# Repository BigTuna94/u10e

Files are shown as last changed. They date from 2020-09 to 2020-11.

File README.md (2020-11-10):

# μ10e

The μ10e, pronounced *Mutiny*, is another take on a DIY ergonomic ortholinear with column stagger split keyboard inspired by such boards as the ErgoDox, Crkbd, Splitreus62, and even the Planck and Boardwalk.

### Sample Layout
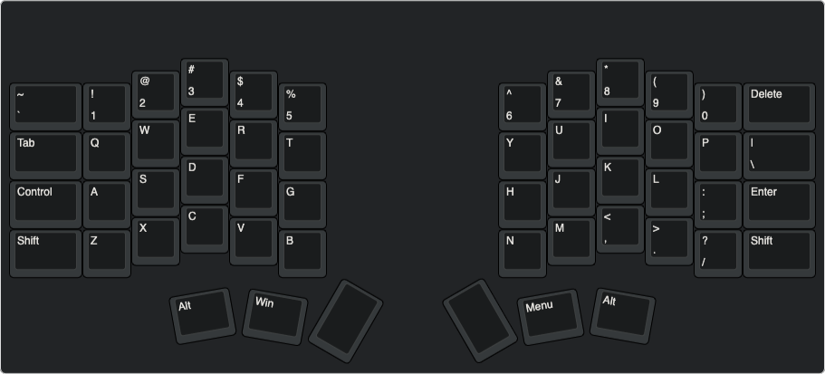
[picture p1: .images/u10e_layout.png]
u10eLayout


### Current PCB Design
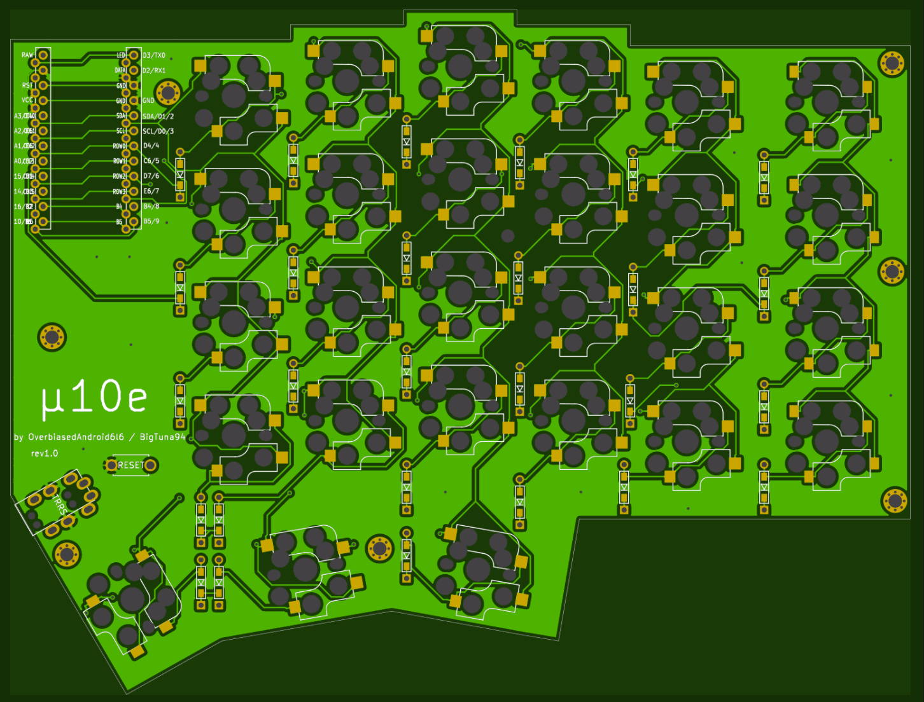
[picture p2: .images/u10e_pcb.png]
u10ePCB


### Goals
The initial inspiration for this board was a Crkbd with 1.5U modifiers, a number row, and Kailh Choc sockets. However, after seeing designs like the Lily58, I've decided it would be even better to support both Choc and MX sockets on the same pcb.

Although the first revision of this board will use a socketed Pro Micro footprint MCU per side, the overall goal of this project is something a little more sofisticated.

### Roadmap
- [x] Create initial schematic and pcb design using pro micro
- [ ] Gather feedback from community

### Potential Future Features
- Encoder footprint below controller
- Move TRRS footprint
- OLED footprint below contoller
- Built in MCU
  - The nice!nano and other new USB-C boards are really good right now.
  - Even though I like this idea, I'll see if there is community interest

### rev1.0 Images
#### MX Mounts
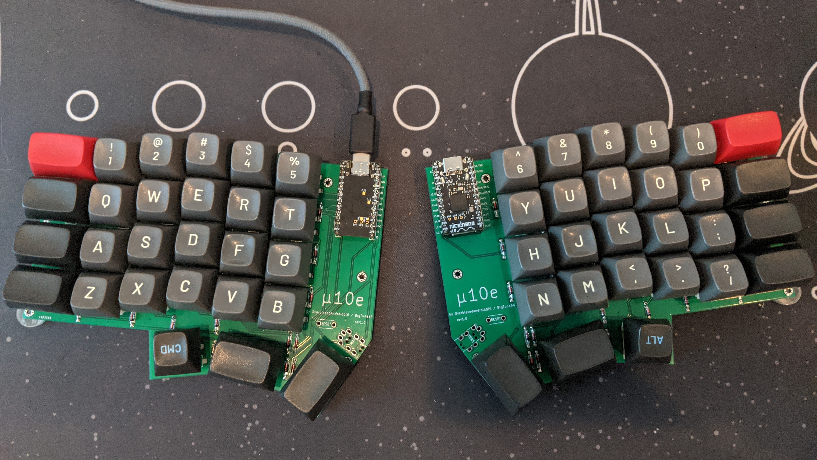
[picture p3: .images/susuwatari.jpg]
MT3 Susuwatari

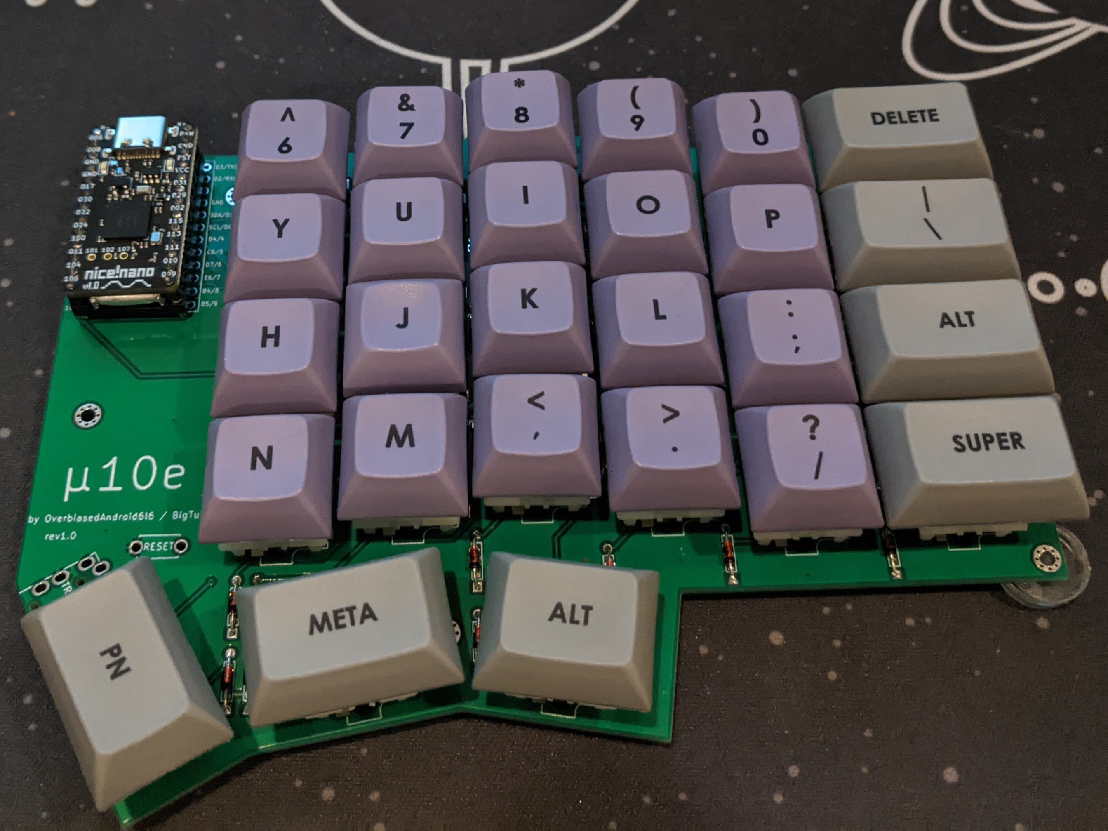
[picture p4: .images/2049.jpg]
DSA 2049

#### Choc Mounts
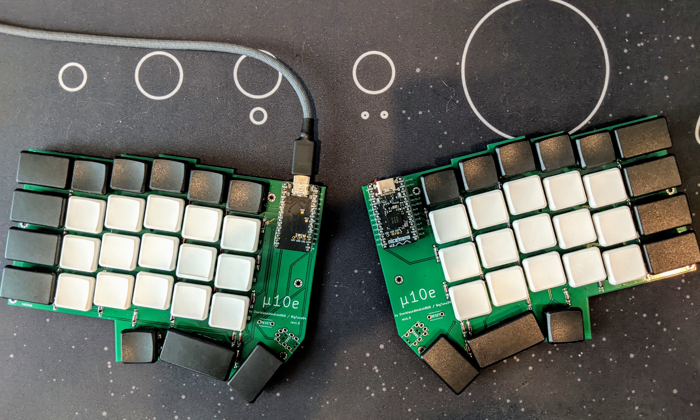
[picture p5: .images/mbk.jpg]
mbk

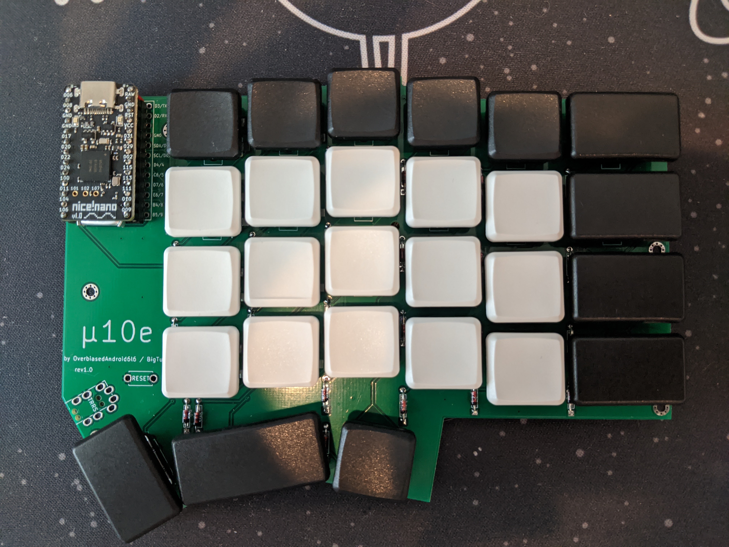
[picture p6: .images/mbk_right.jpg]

#### Socket Closeup
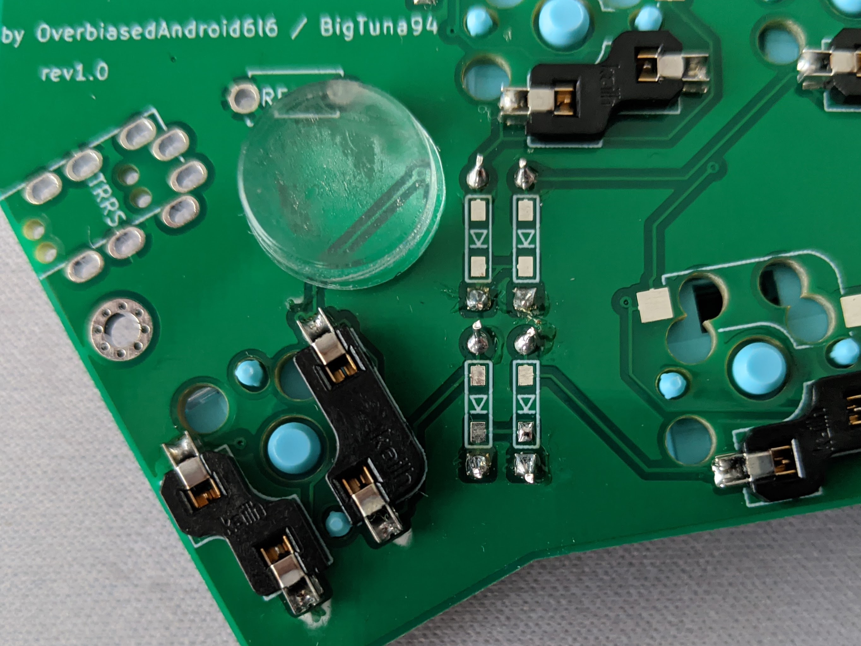
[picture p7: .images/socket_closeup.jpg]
sockets


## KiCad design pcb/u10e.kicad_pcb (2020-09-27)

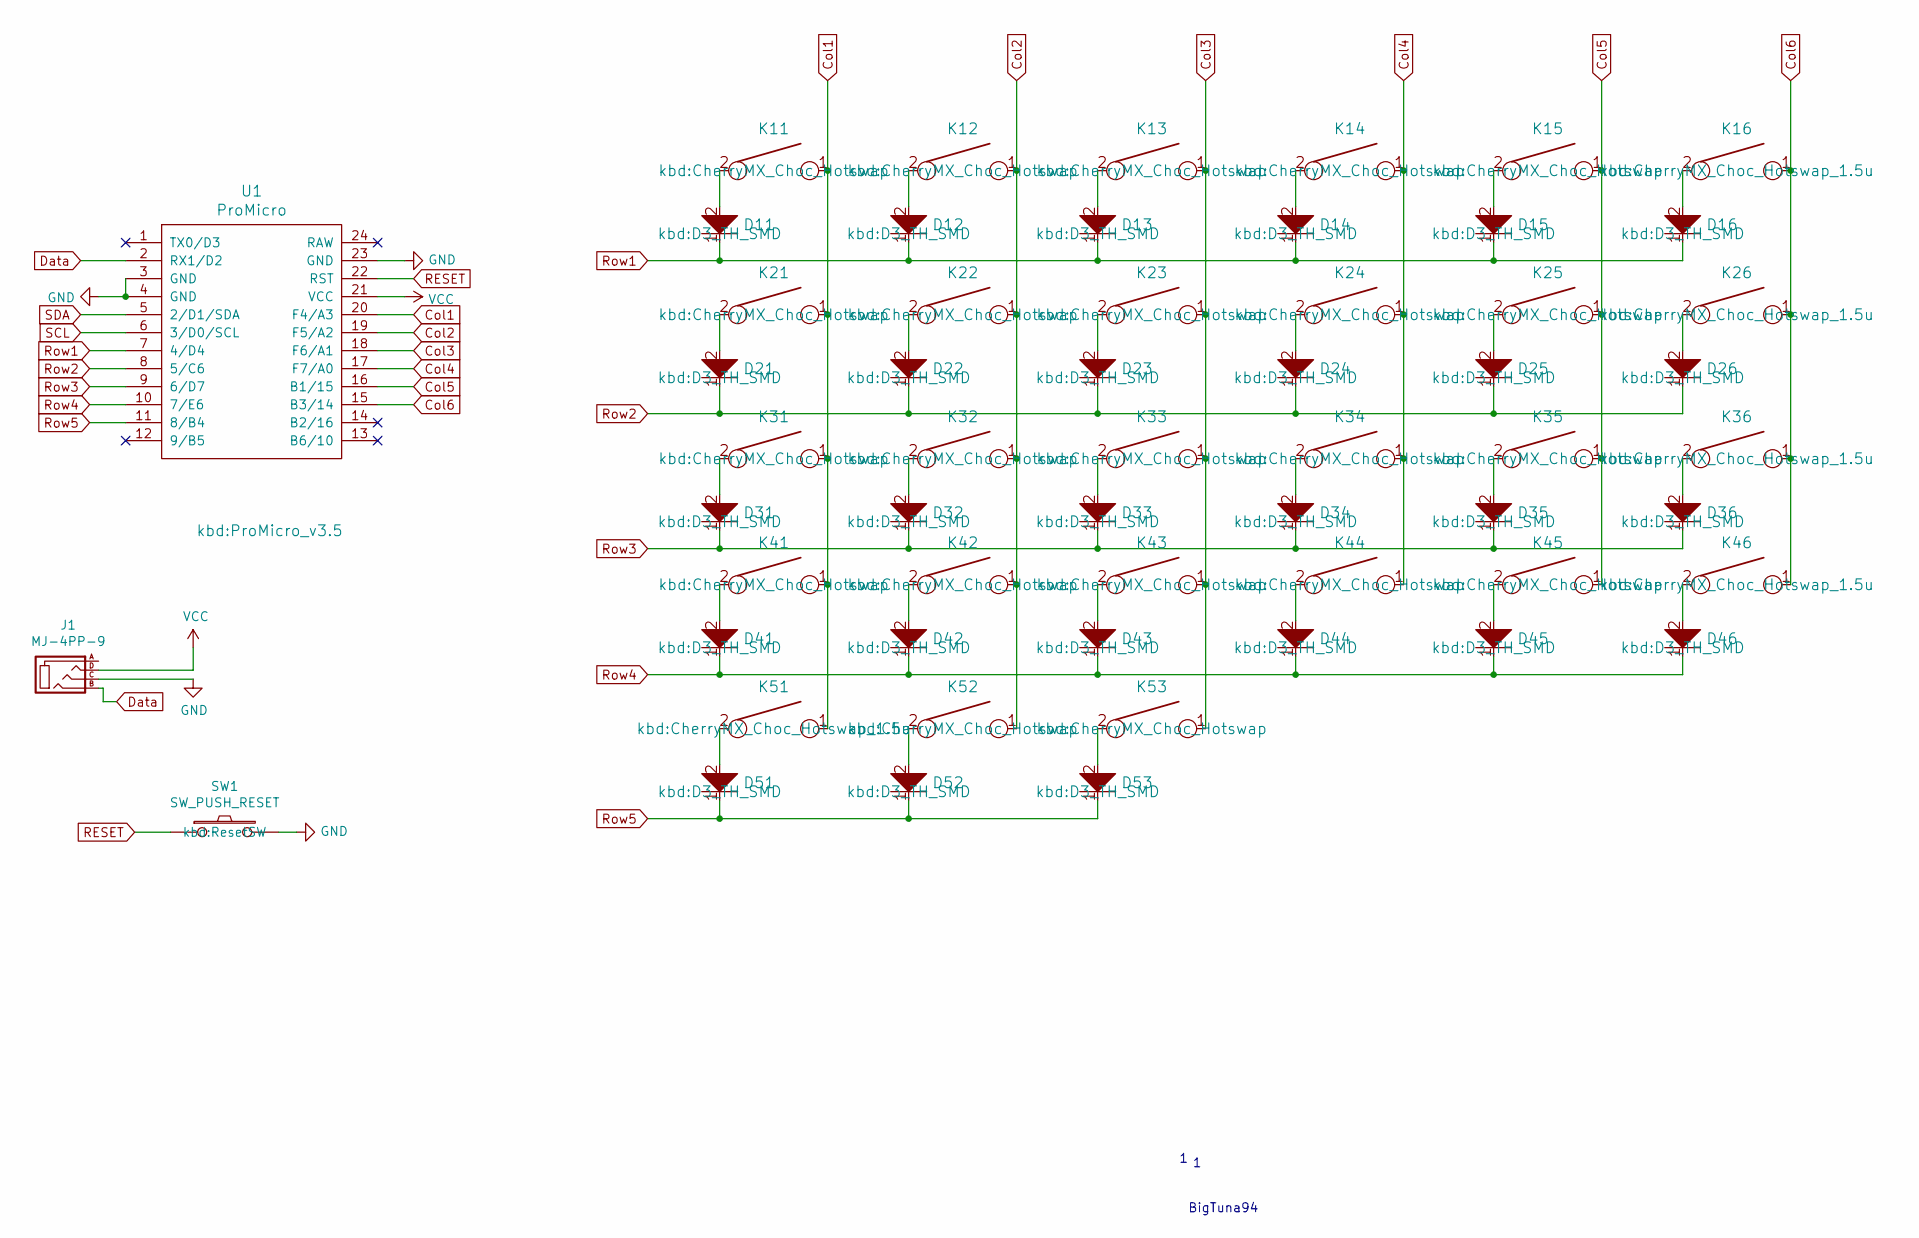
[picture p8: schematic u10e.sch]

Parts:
D11, D12, D13, D14, D15, D16, D21, D22, D23, D24, D25, D26, D31, D32, D33, D34, D35, D36, D41, D42, D43, D44, D45, D46, D51, D52, D53: D; D3_TH_SMD
J1: MJ-4PP-9
K11, K12, K13, K14, K15, K21, K22, K23, K24, K25, K31, K32, K33, K34, K35, K41, K42, K43, K44, K45, K52, K53: KEYSW; CherryMX_Choc_Hotswap
K16, K26, K36, K46, K51: KEYSW; CherryMX_Choc_Hotswap_1.5u
SW1: SW_PUSH_RESET; ResetSW
U1: ProMicro; ProMicro_v3.5

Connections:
Col1: K11.1, K21.1, K31.1, K41.1, K51.1, U1.20 (F4/A3)
Col2: K12.1, K22.1, K32.1, K42.1, K52.1, U1.19 (F5/A2)
Col3: K13.1, K23.1, K33.1, K43.1, K53.1, U1.18 (F6/A1)
Col4: K14.1, K24.1, K34.1, K44.1, U1.17 (F7/A0)
Col5: K15.1, K25.1, K35.1, K45.1, U1.16 (B1/15)
Col6: K16.1, K26.1, K36.1, K46.1, U1.15 (B3/14)
Data: J1.B, U1.2 (RX1/D2)
GND: J1.C, SW1.2, U1.3 (GND), U1.4 (GND), U1.23 (GND)
unnamed: D11.2, K11.2
unnamed: D12.2, K12.2
unnamed: D13.2, K13.2
unnamed: D14.2, K14.2
unnamed: D15.2, K15.2
unnamed: D16.2, K16.2
unnamed: D21.2, K21.2
unnamed: D22.2, K22.2
unnamed: D23.2, K23.2
unnamed: D24.2, K24.2
unnamed: D25.2, K25.2
unnamed: D26.2, K26.2
unnamed: D31.2, K31.2
unnamed: D32.2, K32.2
unnamed: D33.2, K33.2
unnamed: D34.2, K34.2
unnamed: D35.2, K35.2
unnamed: D36.2, K36.2
unnamed: D41.2, K41.2
unnamed: D42.2, K42.2
unnamed: D43.2, K43.2
unnamed: D44.2, K44.2
unnamed: D45.2, K45.2
unnamed: D46.2, K46.2
unnamed: D51.2, K51.2
unnamed: D52.2, K52.2
unnamed: D53.2, K53.2
RESET: SW1.1, U1.22 (RST)
Row1: D11.1, D12.1, D13.1, D14.1, D15.1, D16.1, U1.7 (4/D4)
Row2: D21.1, D22.1, D23.1, D24.1, D25.1, D26.1, U1.8 (5/C6)
Row3: D31.1, D32.1, D33.1, D34.1, D35.1, D36.1, U1.9 (6/D7)
Row4: D41.1, D42.1, D43.1, D44.1, D45.1, D46.1, U1.10 (7/E6)
Row5: D51.1, D52.1, D53.1, U1.11 (8/B4)
SCL: U1.6 (3/D0/SCL)
SDA: U1.5 (2/D1/SDA)
VCC: J1.D, U1.21 (VCC)

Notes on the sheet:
BigTuna94

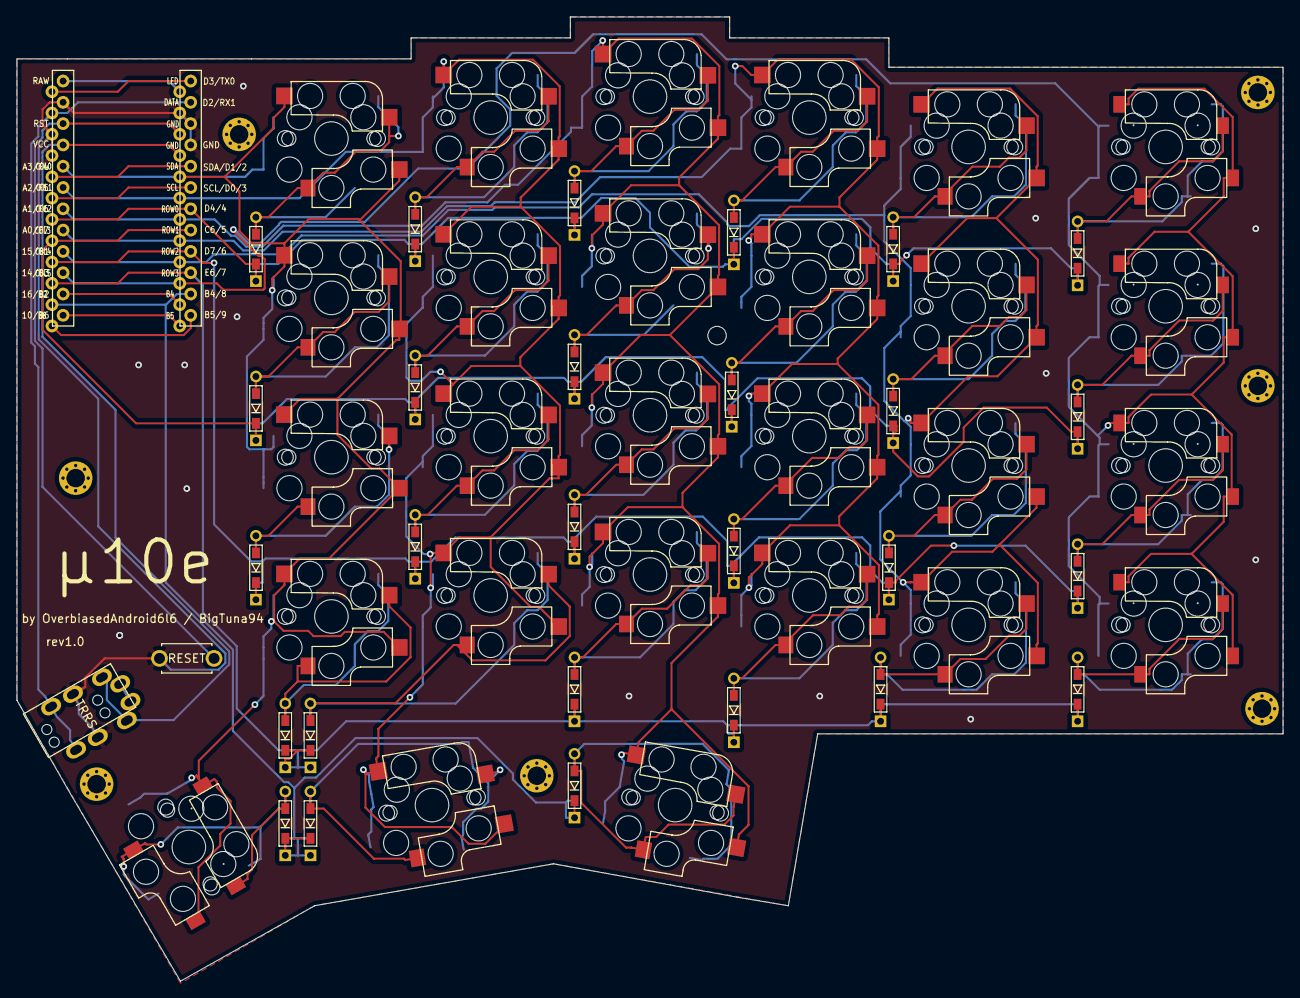
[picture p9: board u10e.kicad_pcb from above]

Board: 2 copper layers, 151.0 x 115.0 mm, 65 parts (0 on the bottom side), 42 nets.

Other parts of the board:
M1, M2, M4, M5, M6, M7, M8: M2_HOLE_v3
M3: MountingHole_2.2mm_M2

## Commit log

2020-09-24 Added current pcb design - schematic complete, parts placed on board but wires not routed
    [u10e.kicad_pcb, u10e.sch]
2020-09-25 moved bottom row to more evenly distribute x space
    [u10e.kicad_pcb]
2020-09-25 added r1 edgecuts
    [u10e.kicad_pcb]
2020-09-26 pre routing commit
    [u10e.kicad_pcb]
2020-09-26 added routes
    [u10e.kicad_pcb]
2020-09-26 Revert "added routes"
    This reverts commit ca254ce08e903a7b231e3a80e900436ff372913d.
    [u10e.kicad_pcb]
2020-09-26 Added mounting holes
    [u10e.kicad_pcb]
2020-09-27 Added routes and silkscreens
    [u10e.kicad_pcb, u10e.kicad_pcb.preroute.kicad_pcb]
2020-09-27 added pcb image
